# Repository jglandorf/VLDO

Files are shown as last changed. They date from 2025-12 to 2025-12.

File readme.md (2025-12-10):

## A Very Low Dropout Regulator Based on G4COL / ND6T

Implemented for use with the [QMX+ HF transceiver](https://qrp-labs.com/qmxp.html).  
PCB designed in KiCAD v9.

References:  
https://www.gqrp.com/limiter.jpg (
via https://groups.io/g/QRPLabs/topic/qmx_battery/111670594)  
http://www.nd6t.com/qrp/VLDO.htm

PCB, top  
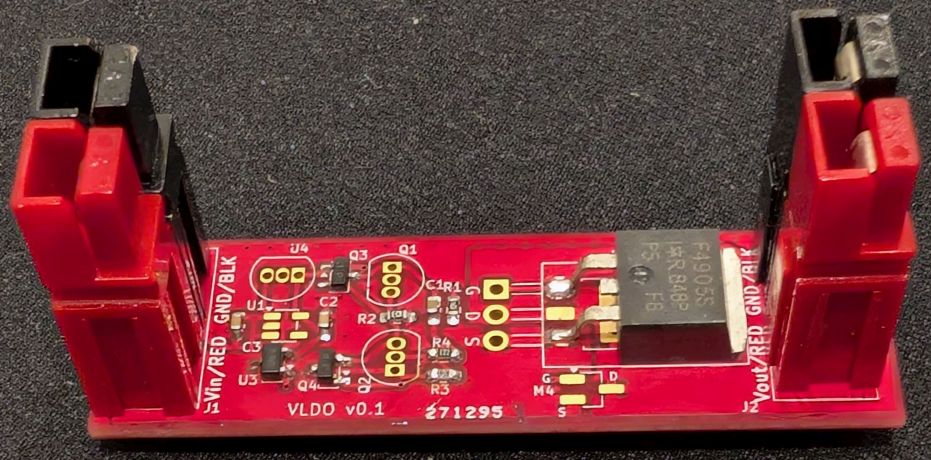
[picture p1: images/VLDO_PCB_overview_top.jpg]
photo, top
  

PCB, bottom  
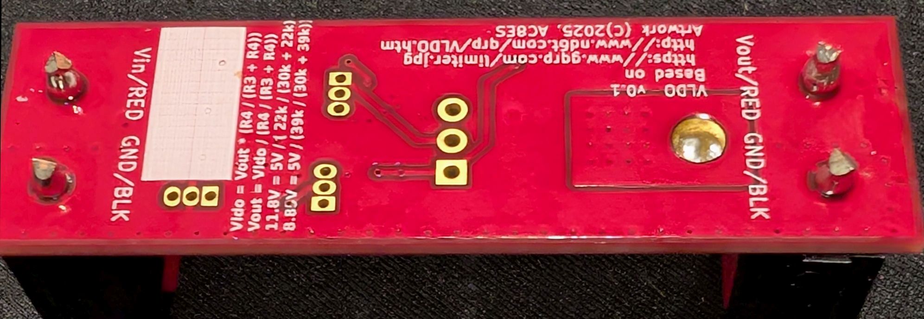
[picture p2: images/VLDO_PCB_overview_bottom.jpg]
photo, bottom
  

Schematic  
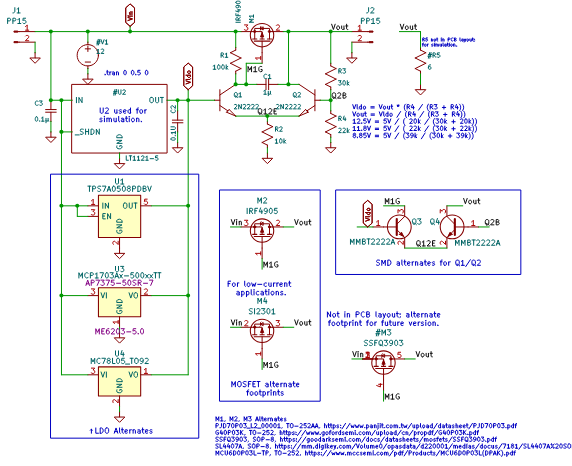
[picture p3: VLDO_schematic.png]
VLDO schematic
  

PCB layout  
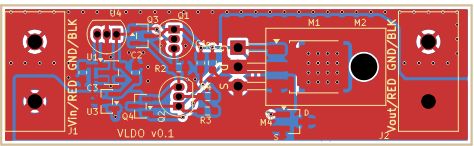
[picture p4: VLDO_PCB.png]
VLDO PCB
  

LTSpice schematic for static simulation  
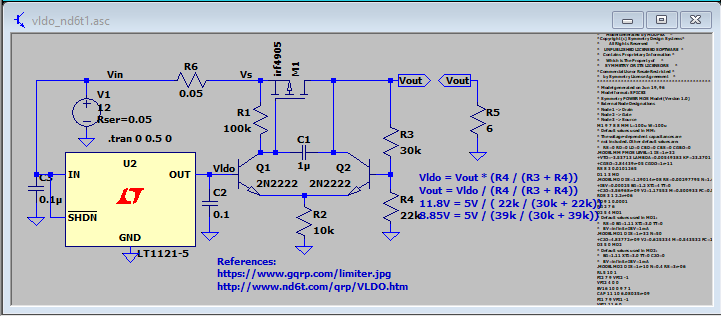
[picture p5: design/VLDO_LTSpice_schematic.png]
LTSpice (static) simulation
  

### Output Voltage with a 5V LDO 
The schematic uses a 5V LDO as the reference voltage.  The output voltage is given by: 
```  
Vldo = Vout * (R4 / (R3 + R4))
Vout = Vldo / (R4 / (R3 + R4))
12.5V = 5V / ( 20k / (30k + 20k))
11.8V = 5V / ( 22k / (30k + 22k))
8.85V = 5V / (39k / (30k + 39k))
```  
In practice, depending on the quality of transistors used, you may need to tweak the value of R3 or R4.

### Parts Tested in Prototype  
The PCB has alternate footprints for the active components so that alternative parts may be tested, or that the PCB may be built mostly surface-mount or through-hole.  

| RefDes | Part | Source | Comments | 
| --- | --- | --- | --- |
| M1 | IRF4905S | https://www.aliexpress.us/item/3256806571411100.html | (TO-263) Works, but runs hotter than expected; Rds_on likely much higher than spec
| M1 | IRF4905 | https://www.aliexpress.us/item/3256806880410046.html | (TO-220 alternate) Part from this supplier does not work well  
| U3 | ME6203A50M3G  | https://www.aliexpress.us/item/3256806655687105.html | (SOT23-3) Works well  
| Q3/Q4 | MMBT2222A  | https://www.aliexpress.us/item/3256806768261444.html | (SOT23-3) Works well  

### Power In/Out Connectors  
The prototype used Anderson PowerPole [PP15/30/45 housings](https://powerwerx.com/anderson-powerpole-colored-housings) with [PP45 crimp pins](https://powerwerx.com/anderson-261g2-powerpole-contact-pp45) as these were on hand -- not the [special PCB-mount pins](https://powerwerx.com/printed-circuit-board-pcb-contact-25amp).  
The PCB is designed for 14 AWG solid wire. To fit 14 AWG solid wire into a PP45 pin (which is designed for 10 AWG wire), it is folded over at the pin end, then soldered into the PP45 pin.  PP30 pins are deisgned for 12-14 AWG wire and should solder in directly.

14 AWG Wire folded over for PowerPole crimp pin  
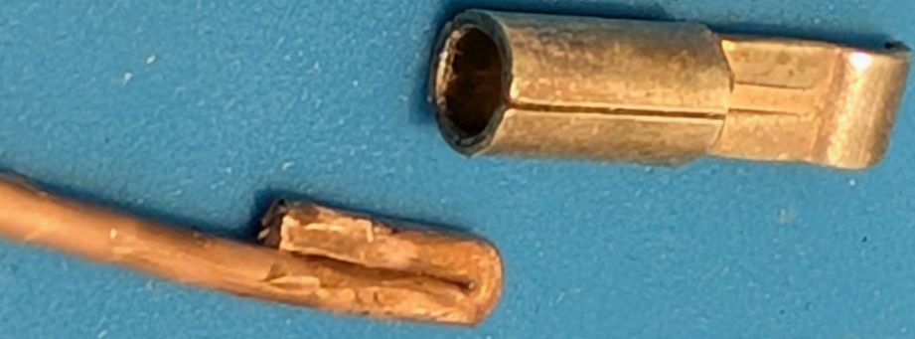
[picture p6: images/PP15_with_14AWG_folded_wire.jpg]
14 AWG Wire folded over for PowerPole crimp pin
  

14 AWG Wire soldered into PowerPole crimp pin  
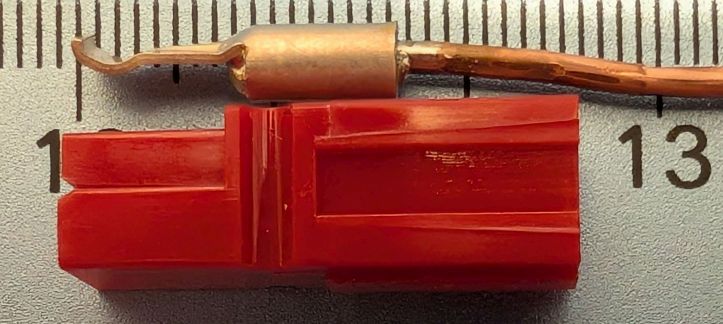
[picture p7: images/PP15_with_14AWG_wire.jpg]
14 AWG Wire soldered into PowerPole crimp pin
  

14 AWG Wire soldered into PCB (be sure to cut excess lead length off)  
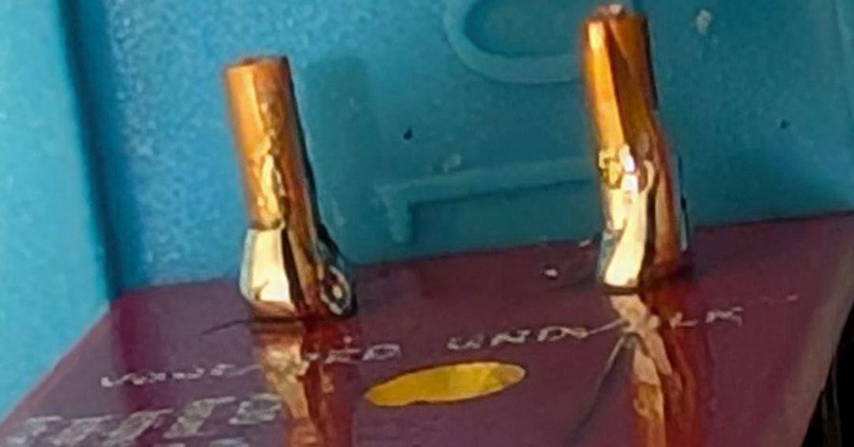
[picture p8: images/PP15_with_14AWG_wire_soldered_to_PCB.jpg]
14 AWG Wire soldered into PCB
  

### Thermal Test  
Although the [QMX+](https://qrp-labs.com/qmxp.html) is specified to consume slightly less than 1 amp at 12 volts, the VLDO prototype was tested with a [WEL-3005 30W constant-current load tester](https://www.hackster.io/john-bradnam/30w-constant-current-load-65ecdd) at 2.5A.  
When using parts from AliExpress or of unknown pedigree, it is recommended that VLDO operating conditions do not exceed those normally expected for the QMX+; i.e., 1A@2 minutes (TX) / 0.1A@2 minutes (RX).   

Vin=13.24, Vout=12V (nominal)  
Iout=2.5A  
Q3/Q4=MMBT2222A  
U3=ME6203-5.0  
M1=IRF4905S (TO-263), __no heatsink__   

Temperature measured with a Cen-Tech 69465 infrared pyrometer aimed at M1's black marked surface, dist= 0.75", or at the bottom of the PCB directly under M1 at a distance of 0.75".  

| Time, seconds | T (deg C), M1 top | T (deg C) PCB bottom |
| --- | --- | --- |
| 0 | 22 | 20.6 |  
| 30 | 41.8 | 37.8 |  
| 60 | 52.8 | 47.4 |  
| 90 | 59.1 | 53.4 |  
| 120 | 62.5 | 56.8 |  
| 180 | 62.6 | 58.8 |  
| 240 | 64.4 | --- |  
| 300 | 65.4 | 60.3 |  
| 360 | 66.6 | 62.6 |  

### Rds(on) Measurement  
Rds(on) Measurement  
The IRF4905S's "ON" resistance, Rds(on), was measured with a 
[WEL-3005](https://www.hackster.io/john-bradnam/30w-constant-current-load-65ecdd) load tester 
and a UT161E multimeter.  For each constant-current test of Id below, current was only turned 
on for 3-4 seconds-- long enough to measure one parameter, but short enough to avoid significantly
heating the device. Power was supplied with a 9Ah LiFePo battery, nominal 12V output.

Device: IRF4905S from [this AliExpress vendor](https://www.aliexpress.us/item/3256806571411100.html).  
Rds(on) = Vds / Id  

| Vin, V |  Id, A | Vds, V | Vout, V | Rds(on)†, Ω |  
| --- | --- | --- | ---- | --- |
| 13.33 | 0.00 | 1.13 | 12.16 | --- |  
| 13.28 | 0.50 | 1.12 | 12.13 | 2.24 |  
| 13.29 | 1.00 | 1.10 | 12.13 | 1.10 |  
| 13.20 | 1.50 | 1.06 | 12.12 | 0.71 |  
| 13.16 | 2.00 | 1.01 | 12.12 | 0.51 |  
| 13.11 | 2.50 | 0.96 | 12.11 | 0.38 |  

†Rds(on) is calculated; other table values are measured.

At 2 amps, the LTSpice [simulation](design/vldo_nd6t1.asc) reports an Rds(on) value of ~21.6mΩ.  The OEM's IRF4905S [datasheet](datasheets/MOSFET_P-Channel-irf4905s-datasheet-en_Infineon.pdf) says it should be ~20mΩ @Vgs = -10V, Id = -42A.
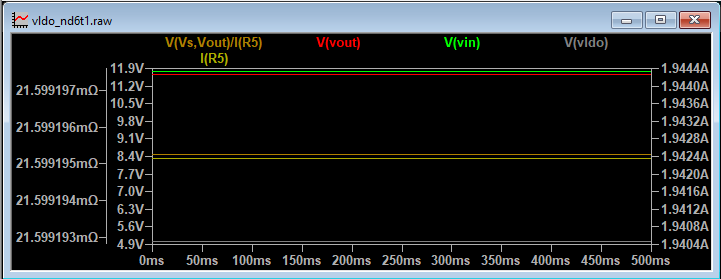
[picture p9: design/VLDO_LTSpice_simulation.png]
LTSpice simulation
  

### Vdo (dropout voltage) Measurement
The IRF4905S's dropout voltage, was measured with a 
[WEL-3005](https://www.hackster.io/john-bradnam/30w-constant-current-load-65ecdd) load tester,
a [UT161E](https://meters.uni-trend.com/product/ut161-series/) multimeter, and a [Hanmatek HM305](http://www.hanmatek.cn/en/index.php?s=/Show/index/cid/14/id/12.html) adjustable power supply.
For each constant-current test of Id, below, current was only turned on for 3-4 seconds-- long enough to measure one parameter, but short enough to avoid significantly
heating the device.  

Dropout Voltage when Vin is close to the nomimal Vout:  
| Vin, V |  Id, A | Vout, V | ΔVout-Vin, V |  
| --- | --- | --- | ---- |
| 12.10 | 0.00 | 12.11 | 0.01 |  
| 12.10 | 0.50 | 12.05 | -0.05 |  
| 12.10 | 1.00 | 12.00 | -0.10 |  
| 12.10 | 1.50 | 11.95 | -0.15 |  
| 12.10 | 2.00 | 11.90 | -0.20 |  
| 12.10 | 2.50 | 11.84 | -0.26 |  

For a nominal QMX+ TX current of somewhat under 1A, the dropout voltage is ~150mV using the IRF4905S from [this AliExpress vendor](https://www.aliexpress.us/item/3256806571411100.html).  Vdo should be lower using a higher quality part.

(Vout - Vin) Voltage at 1A:
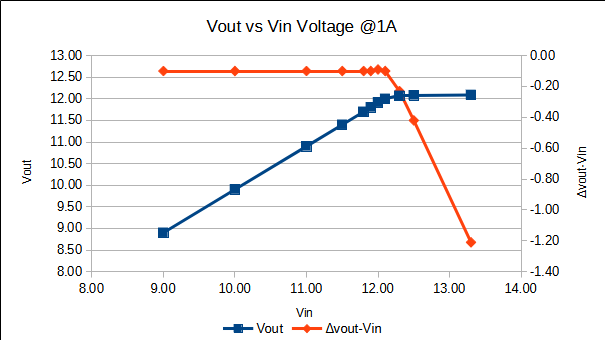
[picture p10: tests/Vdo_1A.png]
Dropout Voltage at 1A
  
Additional data is [here](tests/vldo_tests.ods).

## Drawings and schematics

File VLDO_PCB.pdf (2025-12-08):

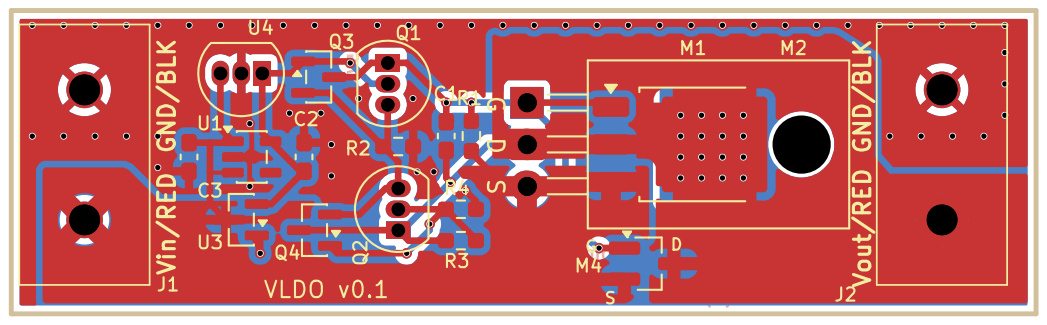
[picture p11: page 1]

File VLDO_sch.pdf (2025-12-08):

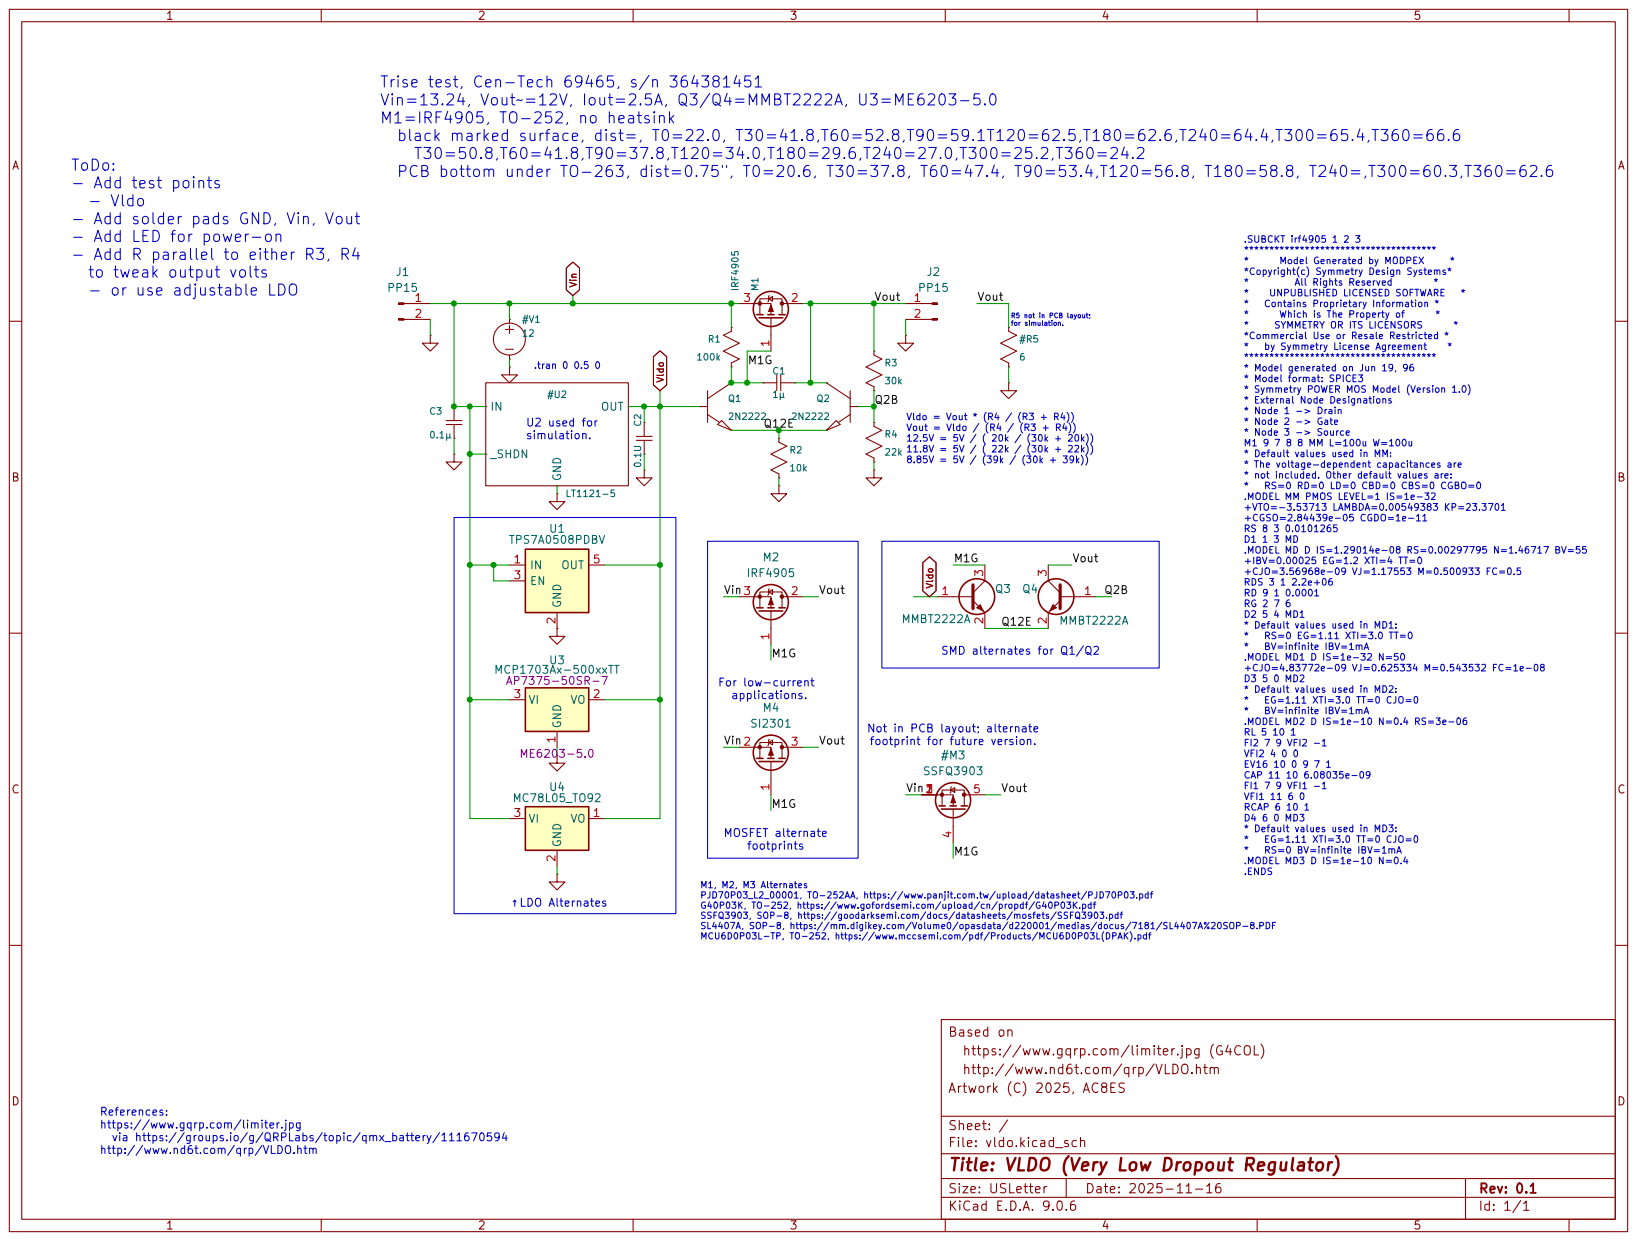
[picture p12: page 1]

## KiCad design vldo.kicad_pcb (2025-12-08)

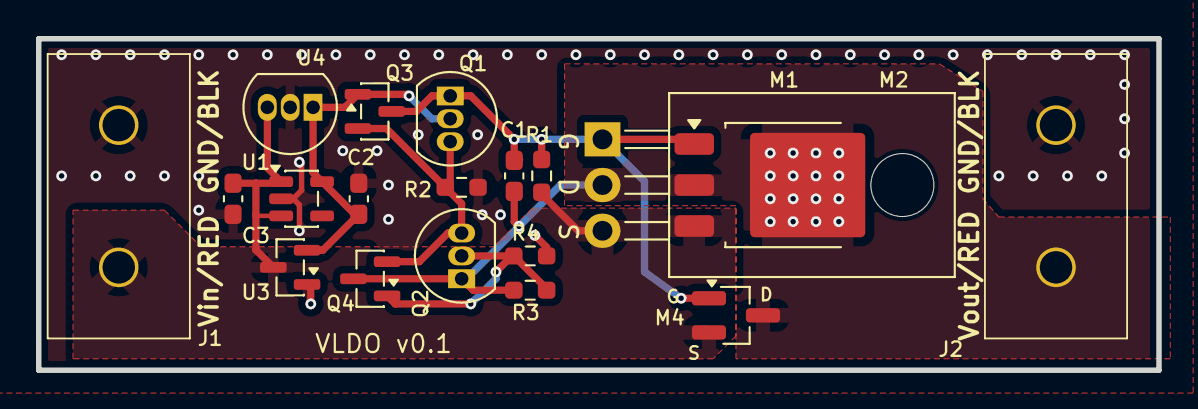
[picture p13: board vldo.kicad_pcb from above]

Board: 2 copper layers, 62.2 x 18.4 mm, 19 parts (0 on the bottom side), 7 nets.

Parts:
C1: 1µ; C_0603_1608Metric_Pad1.08x0.95mm_HandSolder
C2: 0.1; C_0603_1608Metric_Pad1.08x0.95mm_HandSolder
C3: 0.1µ; C_0603_1608Metric_Pad1.08x0.95mm_HandSolder
J1, J2: PP15; Anderson_Powerpole-25A-V_Dual
M1: IRF4905; TO-252-3_TabPin2
M2: IRF4905; TO-220-3_Horizontal_TabDown
M4: SI2301; SOT-23_MOSFET_GSD_Handsoldering
Q1, Q2: 2N2222; TO-92_Inline
Q3, Q4: MMBT2222A; SOT-23
R1: 100k; R_0603_1608Metric_Pad0.98x0.95mm_HandSolder
R2: 10k; R_0603_1608Metric_Pad0.98x0.95mm_HandSolder
R3: 30k; R_0603_1608Metric_Pad0.98x0.95mm_HandSolder
R4: 22k; R_0603_1608Metric_Pad0.98x0.95mm_HandSolder
U1: TPS7A0508PDBV; SOT-23-5
U3: MCP1703Ax-500xxTT; SOT-23
U4: MC78L05_TO92; TO-92_Inline

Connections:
0: C2.2, C3.2, J1.2, J2.2, R2.2, R4.2, U1.2 (GND), U3.1 (GND), U4.2 (GND)
/M1G: C1.2, M1.1 (G), M2.1 (G), M4.1 (G), Q1.1 (C), Q3.3 (C), R1.2
/Q2B: Q2.2 (B), Q4.1 (B), R3.2, R4.1
/Q12E: Q1.3 (E), Q2.3 (E), Q3.2 (E), Q4.2 (E), R2.1
/Vout: C1.1, J2.1, M1.2 (D), M2.2 (D), M4.3 (D), Q2.1 (C), Q4.3 (C), R3.1
Vin: C3.1, J1.1, M1.3 (S), M2.3 (S), M4.2 (S), R1.1, U1.1 (IN), U1.3 (EN), U3.3 (VI), U4.3 (VI)
Vldo: C2.1, Q1.2 (B), Q3.1 (B), U1.5 (OUT), U3.2 (VO), U4.1 (VO)

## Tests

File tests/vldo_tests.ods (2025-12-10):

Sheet: info
Rds(on) Measurement
The IRF4905S's "ON" resistance, Rds(on), was measured with a
[WEL-3005](https://www.hackster.io/john-bradnam/30w-constant-current-load-65ecdd) load tester
and a UT161E multimeter. For each constant-current test of Id, current was only turned
on for 3-4 seconds-- long enough to measure one parameter, but short enough to avoid significantly
heating the device.
Vdo (dropout voltage) Measurement
The IRF4905S's dropout voltage, was measured with a
[WEL-3005](https://www.hackster.io/john-bradnam/30w-constant-current-load-65ecdd) load tester,
a [UT161E](https://meters.uni-trend.com/product/ut161-series/) multimeter, and a [Hanmatek HM305](http://www.hanmatek.cn/en/index.php?s=/Show/index/cid/14/id/12.html) adjustable power supply.
For each constant-current test of Id, below, current was only turned
on for 3-4 seconds-- long enough to measure one parameter, but short enough to avoid significantly
heating the device.
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

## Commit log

2025-12-08 Initial commit for working prototypes
    [vldo-B_Cu.gbr, vldo-B_Mask.gbr, vldo-B_Paste.gbr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]
2025-12-10 Add dropout voltage tests.
    [vldo_tests.ods]

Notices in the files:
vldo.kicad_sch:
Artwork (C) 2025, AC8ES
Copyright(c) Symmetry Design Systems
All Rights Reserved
